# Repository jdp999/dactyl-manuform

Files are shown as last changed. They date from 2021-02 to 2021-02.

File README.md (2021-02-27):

# The Dactyl-ManuForm Keyboard
This is a fork of the [Dactyl](https://github.com/adereth/dactyl-keyboard), a parameterized, split-hand, concave, columnar, ergonomic keyboard.

Imgur

The main change is that the thumb cluster was adapted from the [ManuForm keyboard](https://github.com/jeffgran/ManuForm) ([geekhack](https://geekhack.org/index.php?topic=46015.0)). The walls were changed to just drop to the floor. The keyboard is paramaterized to allow adjusting the following: 

* Rows: 4 - 6 
* Columns: 5 and up
* Row curvature
* Column curvature
* Row tilt (tenting)
* Column tilt
* Column offsets
* Height

I built a 4x5 version (40% size) for myself. The default has a bit more tenting than the Dactyl. See the following model files for configurations that may be most common:

* [40% size, (4x5)](https://github.com/tshort/dactyl-keyboard/blob/master/things/right-4x5.stl)
* [60% size, (5x6)](https://github.com/tshort/dactyl-keyboard/blob/master/things/right-5x6.stl)

## Assembly

### Generating a Design

**Setting up the Clojure environment**
* [Install the Clojure runtime](https://clojure.org)
* [Install the Leiningen project manager](http://leiningen.org/)
* [Install OpenSCAD](http://www.openscad.org/)

**Generating the design**
* Run `lein repl`
* Load the file `(load-file "src/dactyl_keyboard/dactyl.clj")`
* This will regenerate the `things/*.scad` files
* Use OpenSCAD to open a `.scad` file.
* Make changes to design, repeat `load-file`, OpenSCAD will watch for changes and rerender.
* When done, use OpenSCAD to export STL files

**Tips**
* [Some other ways to evaluate the clojure design file](http://stackoverflow.com/a/28213489)
* [Example designing with clojure](http://adereth.github.io/blog/2014/04/09/3d-printing-with-clojure/)

### Printing
Pregenerated STL files are available in the [things/](things/) directory. 
When a model is generated, it also generates a `.scad` model for a bottom plate. 
This can be exported to a DXF file in OpenSCAD.
The [things/](things/) directory also has DXF files for the bottom plate.
When laser cut, some of the inside cuts will need to be removed. 

This model can be tricky to print. 
It's wide, so I've had problems with PLA on a Makerbot with edges warping. 
This can cause the printer to think its head is jammed. 
Even if it successfully prints, warping can cause problems. 
On one print, the RJ-9 holder was squished, so I had to cut down my connector to fit.

If printed at Shapeways or other professional shops, I would not expect such problems. 

### Thingiverse

[The 4x5 STL left/right pair](https://www.thingiverse.com/thing:2349390) from the [things/](things/) directory is in the thingiverse for public printing

### Wiring

Here are materials I used for wiring.

* Two Arduino Pro Micros
* [Heat-set inserts](https://www.mcmaster.com/#94180a331/=16yfrx1)
* [M3 wafer-head screws, 5mm](http://www.metricscrews.us/index.php?main_page=product_info&cPath=155_185&products_id=455)
* [Copper tape](https://www.amazon.com/gp/product/B009KB86BU)
* [#32 magnet wire](https://www.amazon.com/gp/product/B00LV909HI)
* [#30 wire](https://www.amazon.com/gp/product/B00GWFECWO)
* [3-mm cast acrylic](http://www.mcmaster.com/#acrylic/=144mfom)
* [Veroboard stripboard](https://www.amazon.com/gp/product/B008CPVMMU)
* [1N4148 diodes](https://www.amazon.com/gp/product/B00LQPY0Y0)
* [Female RJ-9 connectors](https://www.amazon.com/gp/product/B01HU7BVDU/)

I wired one half using the traditional approach of using the legs of a diode to form the row connections. 
(I'm not great at soldering, so this was challenging for me.)
For this side, I used magnet wire to wire columns. That worked okay. 
The magnet wire is small enough, it wants to move around, and it's hard to tell if you have a good connection.

Imgur

For another half, I used stripboard for the row connections. 
This allowed me to presolder all of the diodes. 
Then, I hot-glued this in place and finished the soldering of the other diode ends. 
I like this approach quite a lot. 
Connections for the diodes were much easier with one end fixed down. 
On this half, I also used copper tape to connect columns. 
This worked a bit better than the magnet wire for me. 
For a future version, I may try just bare tinned copper wire for columns (something like #20). 
With the stripboard, it's pretty easy keeping row and column connections separate.

Imgur

Note that a telephone handset cable has leads that are reversed, so take this into account when connecting these leads to the controller.

The 3D printed part is the main keyboard. 
You can attach a bottom plate with screws. 
The case has holes for heat-set inserts designed to hold 3- to 6-mm long M3 screws. 
Then, I used wafer-head screws to connect a bottom plate. 
If wires aren't dangling, a bottom plate may not be needed. 
You need something on the bottom to keep the keyboard from sliding around. 
Without a plate, you could use a rubber pad, or you could dip the bottom of the keyboard in PlastiDip.

For more photos of the first complete wiring of v0.4, see [Imgur](http://imgur.com/a/v9eIO).

This is how the rows/columns wire to the keys and the ProMicro
Wire Diagram

#### Alternative row-driven wiring diagram for ProMicro:

NOTE: you also make sure the firmware is set up correctly (ex: change row pins with col pins)

Left Wire Diagram

Left Wire Diagram


### Firmware

Firmware goes hand in hand with how you wire the circuit. 
I adapted the QMK firmware [here](https://github.com/tshort/qmk_firmware/tree/master/keyboards/dactyl-manuform). 
This allows each side to work separately or together. 
This site also shows connections for the Arduino Pro Micro controllers.

## License

Copyright © 2015-2017 Matthew Adereth and Tom Short

The source code for generating the models (everything excluding the [things/](things/) and [resources/](resources/) directories is distributed under the [GNU AFFERO GENERAL PUBLIC LICENSE Version 3](LICENSE).  The generated models and PCB designs are distributed under the [Creative Commons Attribution-NonCommercial-ShareAlike License Version 3.0](LICENSE-models).

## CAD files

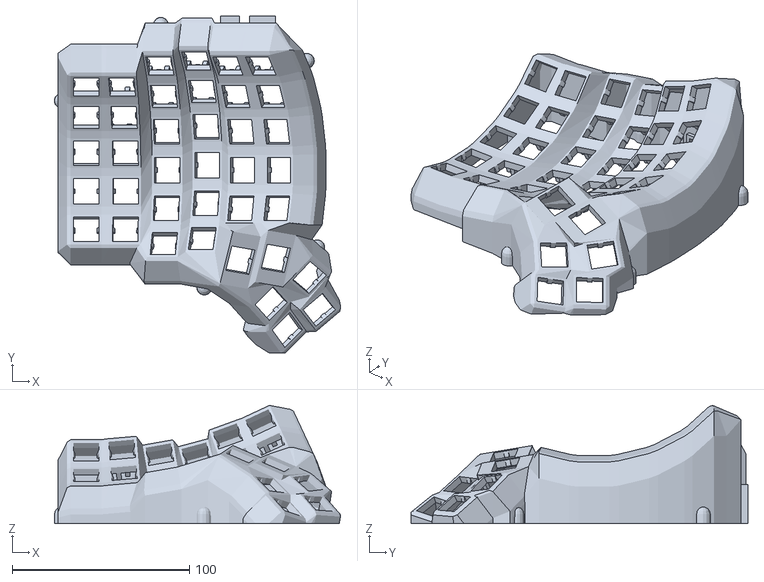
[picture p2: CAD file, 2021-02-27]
things/left-6x6.stl
161.7 x 190.2 x 66.8

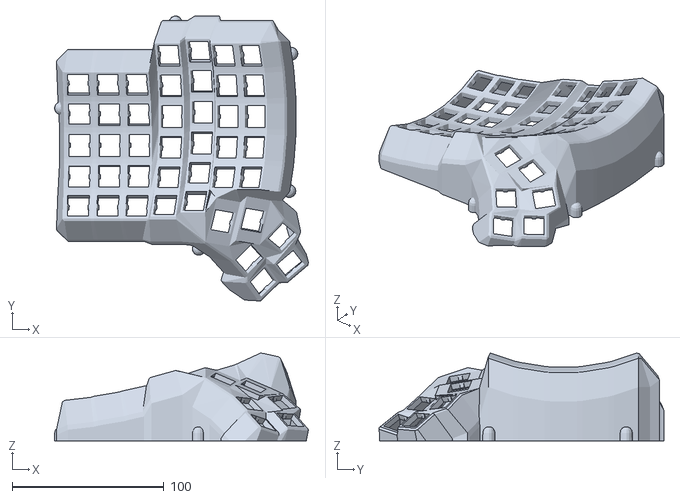
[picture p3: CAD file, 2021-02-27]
things/left6x7-tuned.stl
167.3 x 187.6 x 57.9

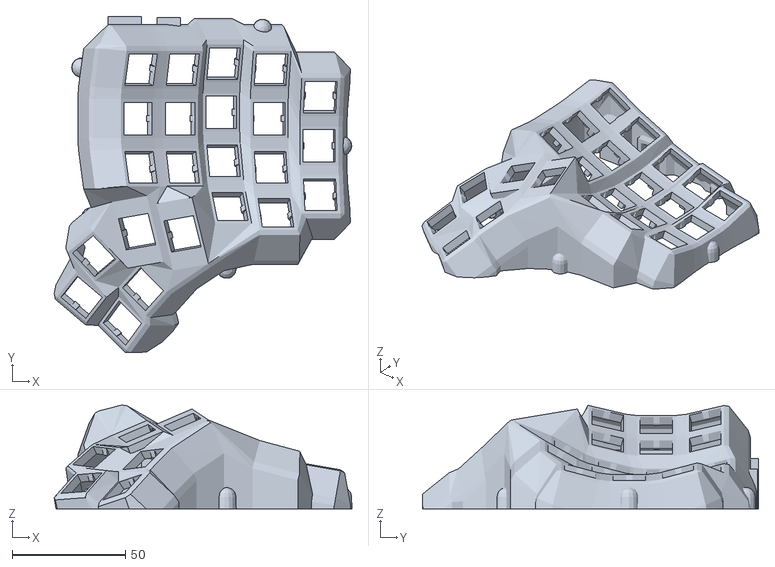
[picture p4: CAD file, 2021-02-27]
things/right-4x5.stl
131.5 x 148.4 x 45.8

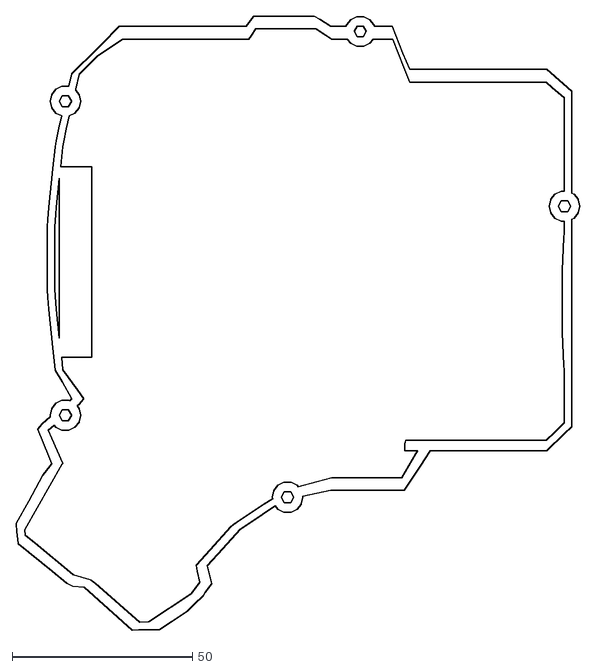
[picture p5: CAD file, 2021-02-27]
things/right-5x6-plate.dxf
156.5 x 170.5

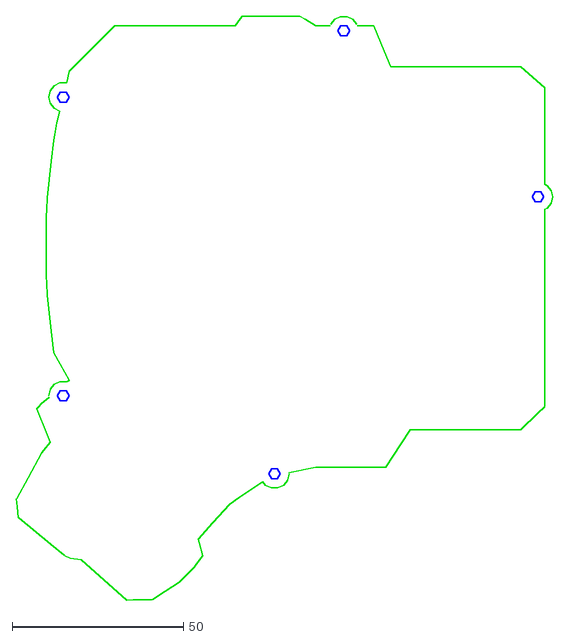
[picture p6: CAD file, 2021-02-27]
things/right-5x6-plate-ready-to-cut.dxf
156.5 x 170.5

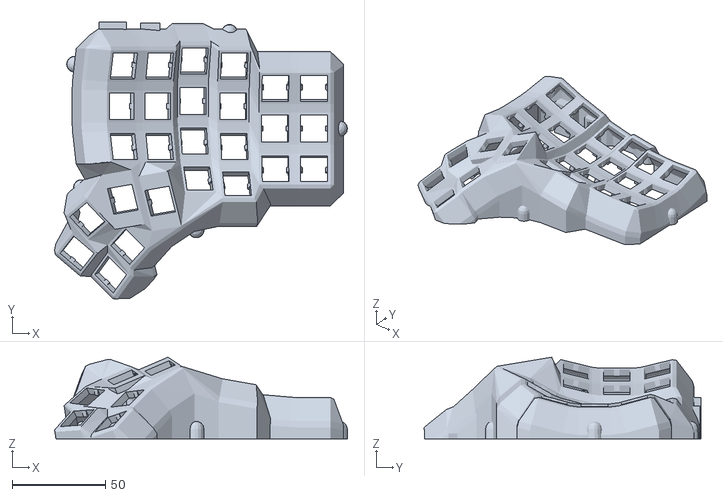
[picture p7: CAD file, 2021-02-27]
things/right-4x6.stl
157.2 x 148.4 x 43.8

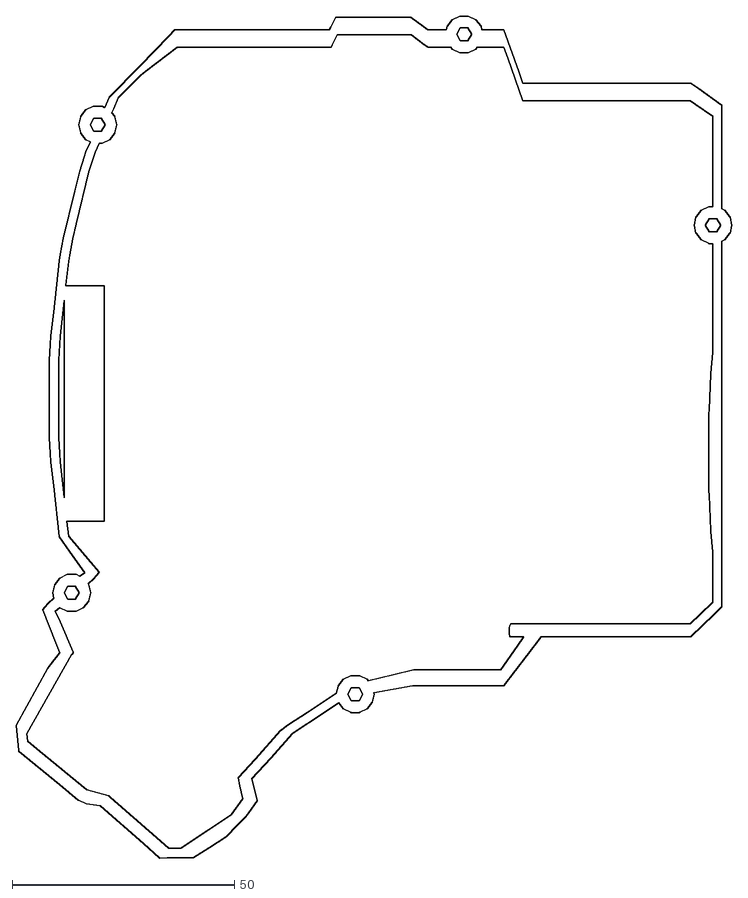
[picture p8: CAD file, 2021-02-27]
things/right-6x6-plate.dxf
160.9 x 189.3

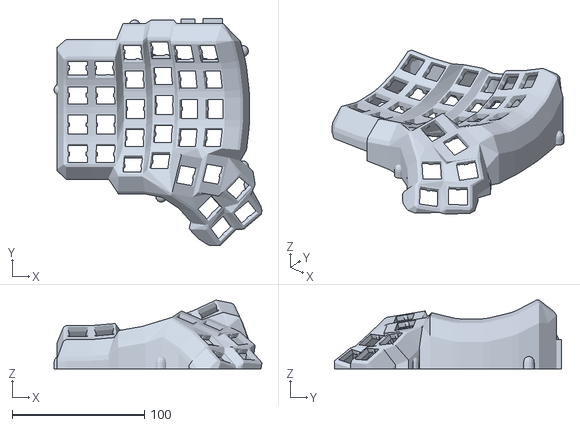
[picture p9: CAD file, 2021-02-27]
things/left-5x6.stl
157.2 x 171.5 x 52.1

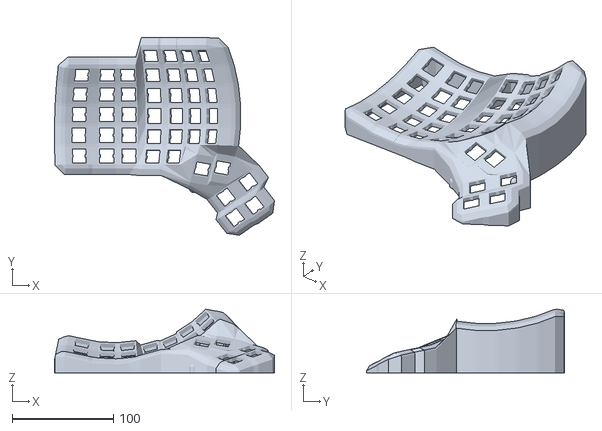
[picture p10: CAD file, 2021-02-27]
things/left6x7-MOD2.stl
216.9 x 194.8 x 62.7

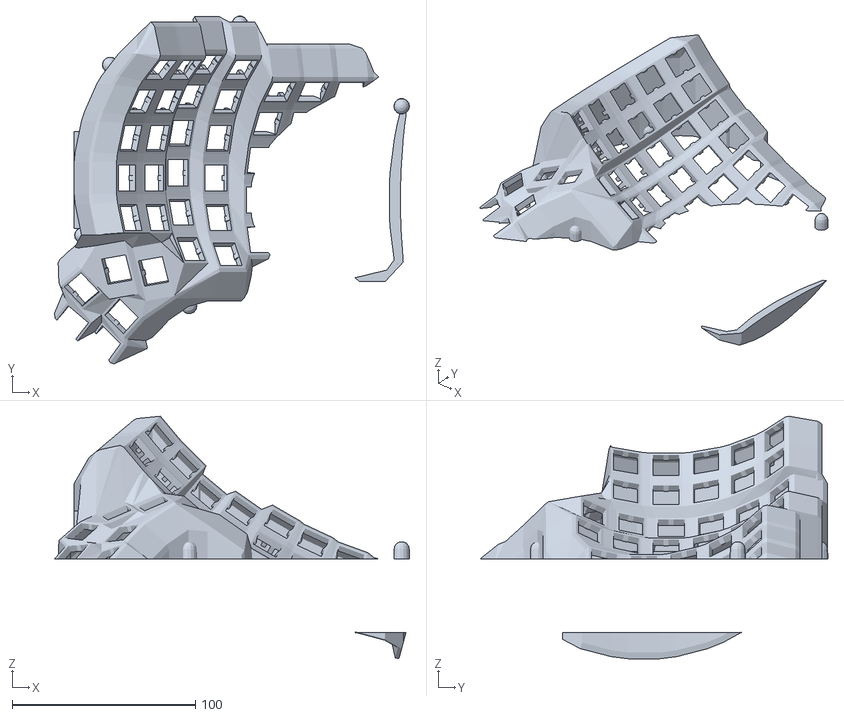
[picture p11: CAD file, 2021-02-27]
things/right6x8.stl
193.5 x 189.5 x 132.2

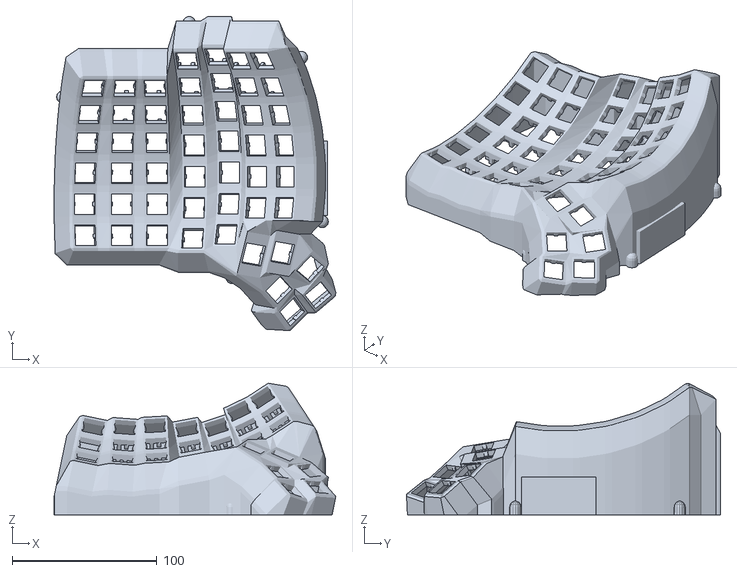
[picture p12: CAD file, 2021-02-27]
things/left7x7.stl
194.4 x 216.7 x 90.8

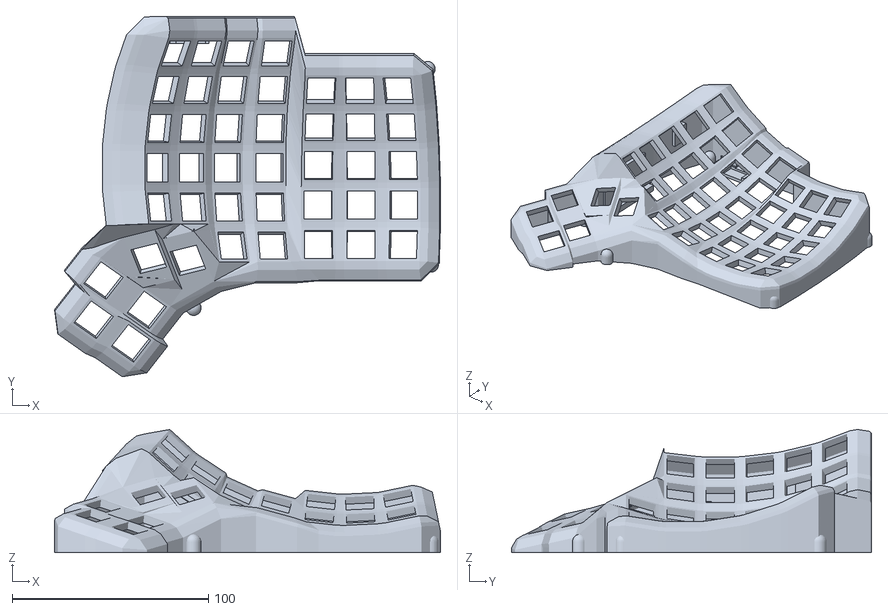
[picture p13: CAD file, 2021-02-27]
things/right6x7_short.stl
196.8 x 183.8 x 62.7

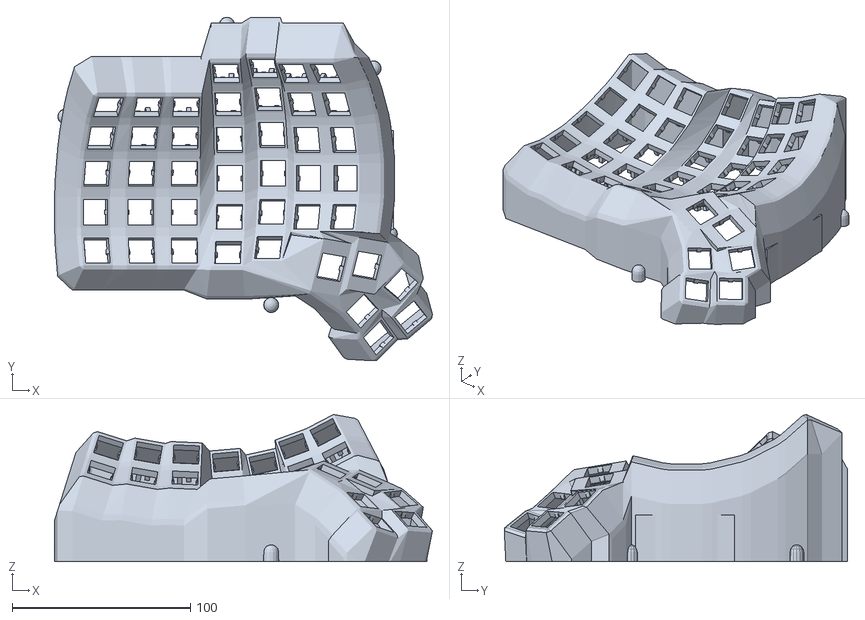
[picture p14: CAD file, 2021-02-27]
things/left6x7.stl
212.0 x 192.6 x 82.5

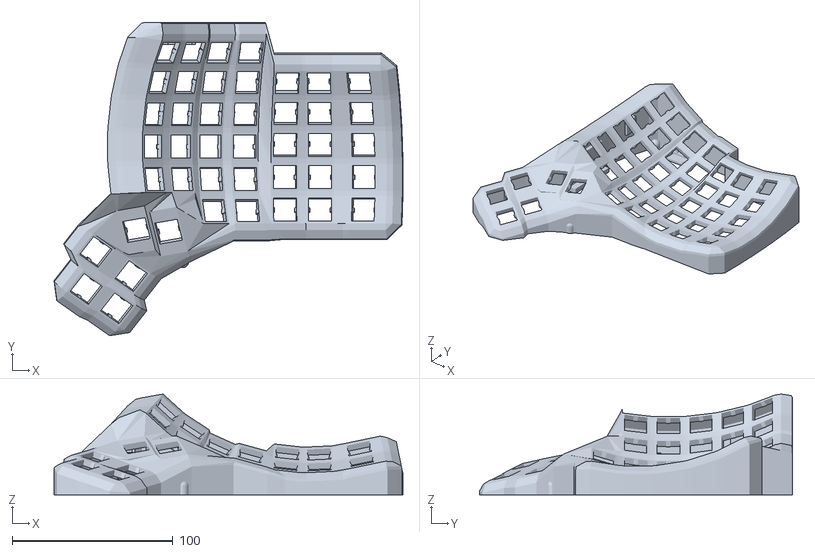
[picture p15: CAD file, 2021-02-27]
things/right6x7-MOD2stl.stl
216.9 x 194.8 x 62.7

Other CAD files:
things/right.6x7_tuned.stl
things/left-4x6.stl
things/left-4x5.stl
things/right7x7.stl
things/left6x7_short.stl
things/right-4x5-plate.dxf
things/right-4x6-plate.dxf
things/right-5x6.stl
things/right-6x6.stl
things/right-plate.dxf
things/right.stl
things/right6x7-MOD1.stl
things/right6x7.stl

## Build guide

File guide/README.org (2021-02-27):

* Preparation and Cost
  Get all the parts / raw material:
  - For the 3D printing there are two options:
    1. Filament, which is the basis for 3D printing. Luckily I could print at my work-place
       which reduced the cost from 210€ to 70€. The kind of filament you need depends on the 3D
       printer you have available.
    2. Buy the printout of adareth's model at shapeways for 210€ over here
       http://www.shapeways.com/designer/adereth/creations
  - Decide on the switches
    - If you are going to invest a whole lot of time and money for a custom keyboard instead of
      buying one for 10€ I'd recommend to use your favorite switch-type. To make a
      well-informed decision I bought a switch-tester for this from massdrop and decided on
      Cherry MX Whites. https://www.massdrop.com/buy/varmilo-switch-tester-with-anodized-case
    - I ordered 70 Cherry MX Whites from here:
      https://mechanicalkeyboards.com/shop/index.php?l=product_detail&p=847
  - Decide on the key caps
    - On the glamour-Shot you can see the 1976 keycap set, it used to be sold over here:
      http://pimpmykeyboard.com/sa-1976-keycap-set/ but the link is dead right now. You could
      try this link: https://www.massdrop.com/buy/nineteenseventysix-sa-keycap-set but it is a
      massdrop which is way different from usual online-stores. If you find a site that sells
      these make sure you get the right amount and type of keys according to the layout
    - I got the "TKL Base Set + TKL Modifier" from over here:
      http://pimpmykeyboard.com/dsa-pbt-abs-blank-keycap-sets/ but I'm still two long keys
      short, I will have to order those specifically and I have a bunch of keys I don't use
      left-over.
  - The USB-Cable that connects the keyboard to your computer
    - It's an USB 2.0 to USB Mini-B cable, make sure you get one that is 2 meters long, it
      really makes handling the keyboard so much more comfortable
    - https://www.amazon.de/gp/product/B00NH11N5A/
  - The main controller (right half)
    - A Teensy 2.0, I got that one from here: https://www.pjrc.com/store/teensy.html
  - The chip, connectors and cable to give life to the left half
    - TTRS cable and jacks
      - Got my TTRS cable from here: http://www.digikey.de/product-search/de?keywords=839-1257-ND
      - Got my TTRS jacks from here: http://www.digikey.de/product-search/de?keywords=CP-43514-ND
    - MCP23018 16 bit IO Expander
      - Got mine from here: http://www.digikey.de/product-search/de?keywords=MCP23018-E%2FSP-ND

  What I spend on my keyboard (should give you a rough estimate for your build):
  | item                              | cost |
  |-----------------------------------+------|
  | filament                          |   70 |
  | switch-tester                     |   30 |
  | key-caps                          |   70 |
  | teensy 2.0                        |   30 |
  | switches                          |   60 |
  | usb cable                         |   10 |
  | IO Expander, TTRS jacks and cable |   30 |
  |-----------------------------------+------|
  | overall cost                      |  300 |
  #+TBLFM: @9$2=vsum(@2$2..@8$2)

  My choices / advantages:
  - Using the soldering iron at the uni-workshop for free
  - 76 Diodes for free
  - Soldering wire and copper for free
  - All the resistors used for free (5 resistors are used)
  - Several files for working out the rough edges of the 3D-printout

  Depending on what you have available you might spend more or less money than me, 300€ however
  is a good rough estimate.

  After all the parts have arrived it is safe to move on to the next section.

* Wiring
  It is assumed that you have printed the casing successfully.

  1) Plug the switches into the Casing, no glue is needed, the casing provides the perfect fit.
  2) Put the keycaps on the switches
     - Note that in the pictures here some of the long keys on the thumb-part are too short,
       that's why it doesnt look symmetrical

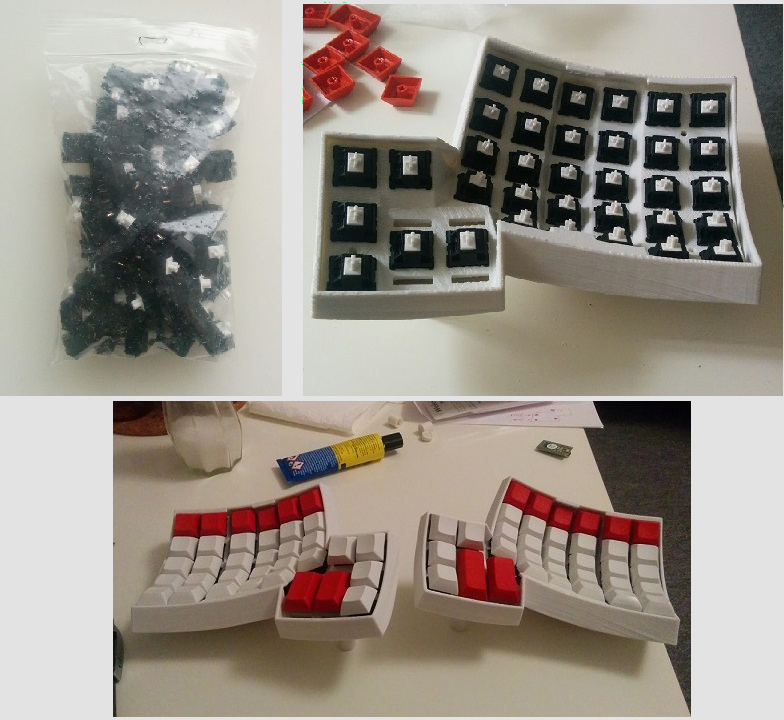
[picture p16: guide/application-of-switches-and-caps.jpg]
  

  Now going further on in the guide there are two options
  1. The first option is to print flexible PCBs. The advantage is that you save alot of wiring
     business, everything looks rather clean and you dont have to worry about your cables being too
     thick such that the casing doesnt close. However if you don't have the means to print out such
     PCBs there is the second option, wiring everything by hand.
     - The guide for this PCB-option is very rough indeed and it doesnt include the firmware
       used. Wiring and firmware play extremely close together, wiring before knowing your
       firmware is like buying a shoe without measuring your feet before. For this option
       information about the exact firmware is not published, this in addition to the fact that
       the pictures in this rough guide are incomplete makes this option extremely
       beginner-unfriendly. Going in blind-sided like this may lead to one of these things:
       1. reprogramming huge parts of the firmware to match your wiring which comes with a ton of
          debugging
       2. rewiring to adapt to what the firmware expects, which may easily double your work here
     - [[Route 1: Dactyl Flexible PCB Rough Guide]]
  2. The second option is to hand-wire everything. For people like me who had never soldered before
     this was great pain and pleasure.
     - Here too firmware and wiring go hand in hand, you pretty much have to have a detailed look
       at the firmware you are using before wiring anything. I provide my modification of the
       "ergodox-firmware" over here: https://github.com/BubblesToTheLimit/ergodox-firmware
       - TODO: Make a successfull pull-request, such that it is available in the official
         ergodox-firmware
     - Some of the steps of this guide may not be described in much detail, but in contrast to
       option one there is a whole lot more of information.
     - [[Route 2: Dactyl Hand-Wiring Guide]]

** Route 1: Dactyl Flexible PCB Rough Guide
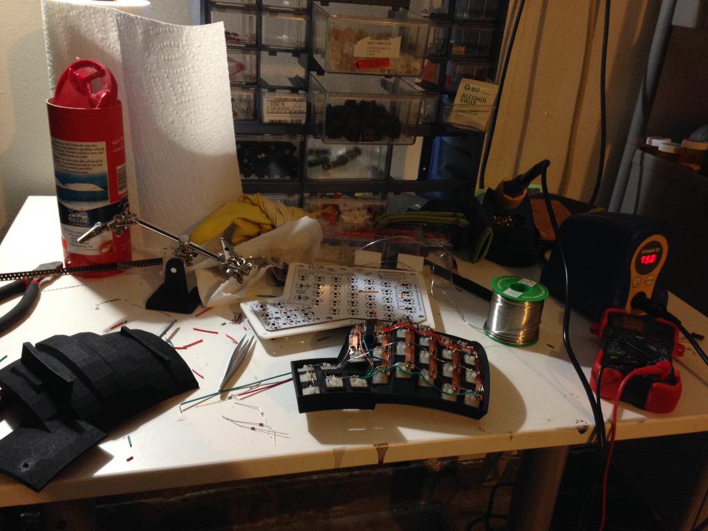
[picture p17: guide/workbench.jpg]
   

   For now, take a look at the images and try to figure things out, I know that's not great (it's
   better than nothing!)

*** Making the PCB
    Get two sheets of 6in square Pyralux™. Use the Toner Transfer method to etch the Pyralux sheets as
    you would a usual PCB

    #+BEGIN_QUOTE
    NOTE: If you only have an Inkjet make photocopies of the print out,
    voilà Toner based copies!
    #+END_QUOTE

    [[http://www.instructables.com/id/Toner-transfer-no-soak-high-quality-double-sided/][Here'sa handy toner transfer guide ...]]

    Print these PCB designs out...

    Left hand:

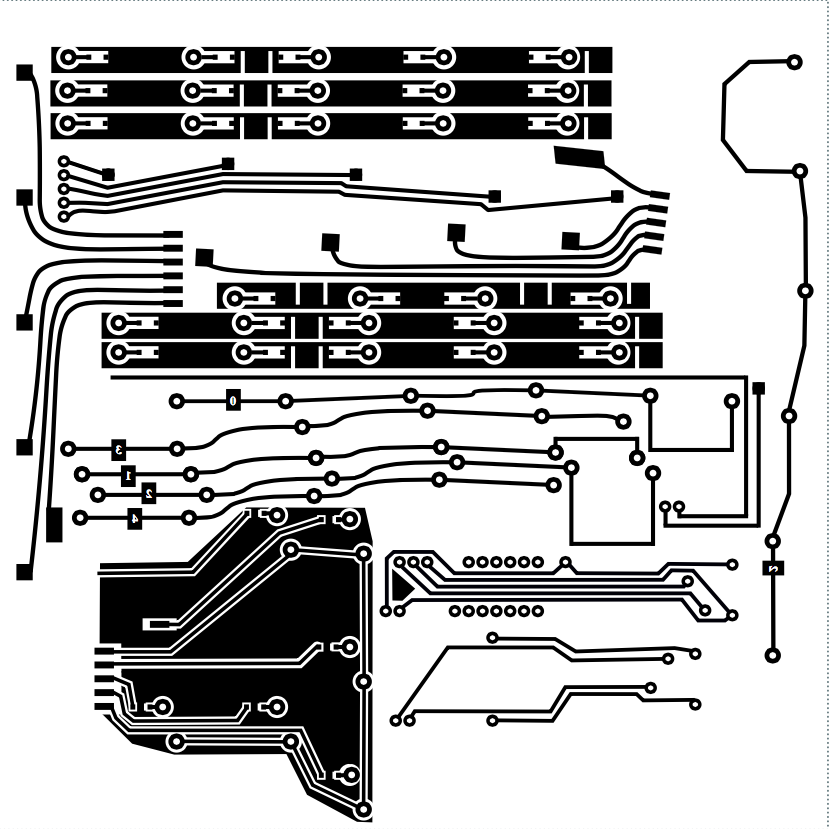
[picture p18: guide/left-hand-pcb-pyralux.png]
    

    Right hand:

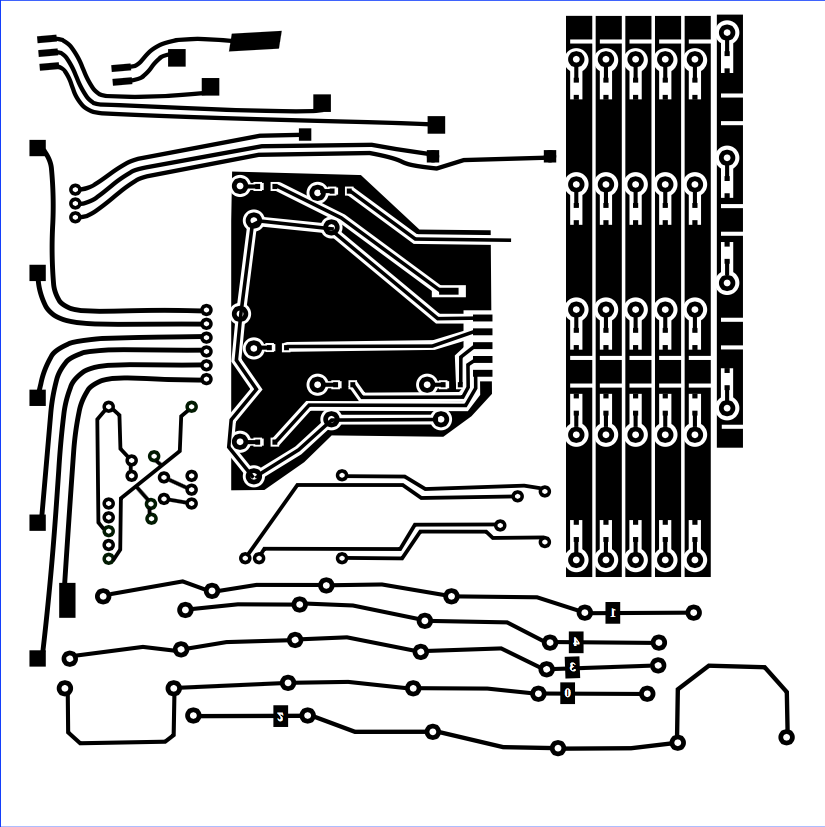
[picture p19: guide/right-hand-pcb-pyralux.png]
    

    When you're done etching, you'll need to carefully cut the pcb into pieces... See the images
    below.

*** Applying the PCB to the electronical parts
    The thumb cluster pcb for the left hand:

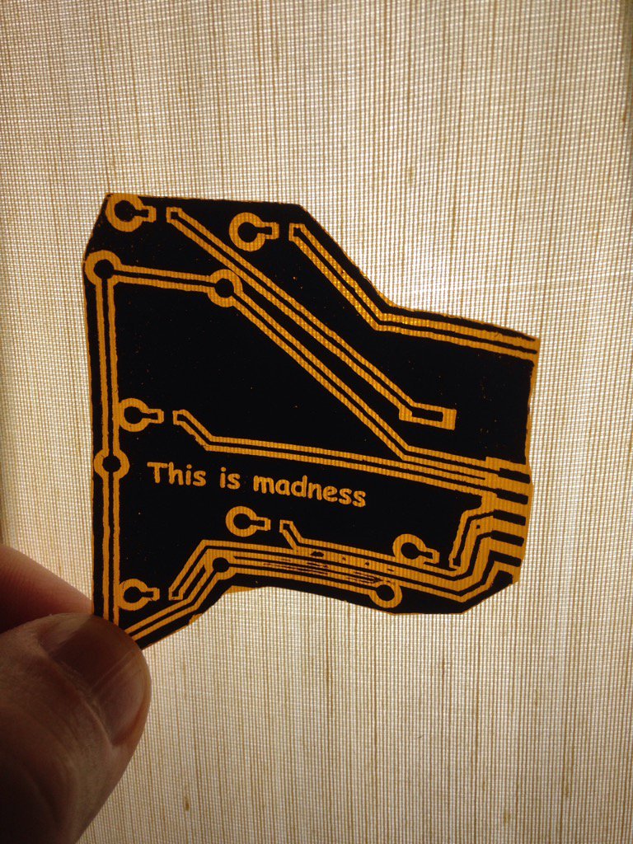
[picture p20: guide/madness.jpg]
    

    Solder the MCP like so:

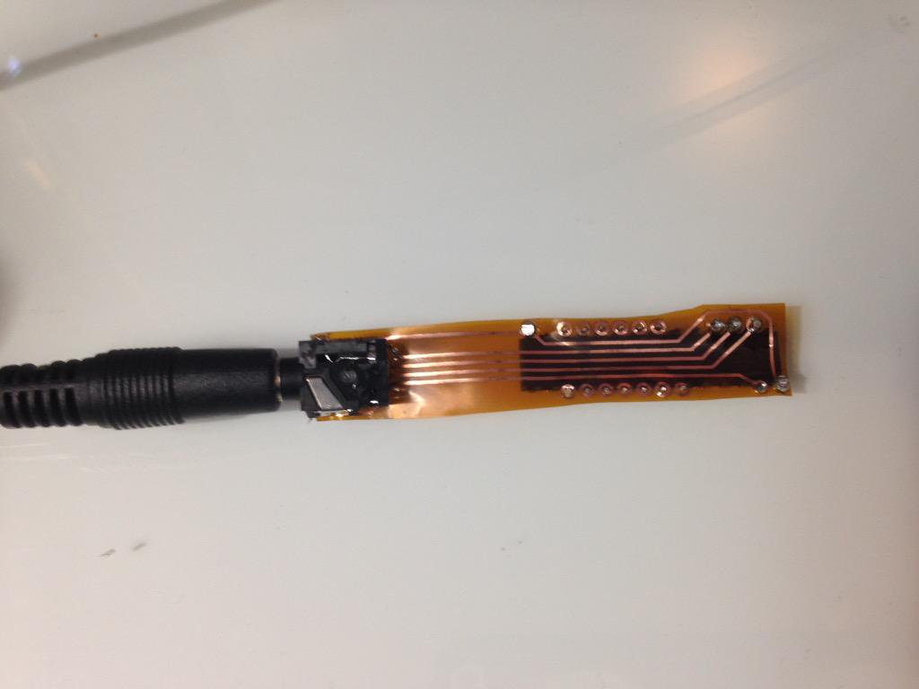
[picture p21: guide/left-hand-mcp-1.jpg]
    
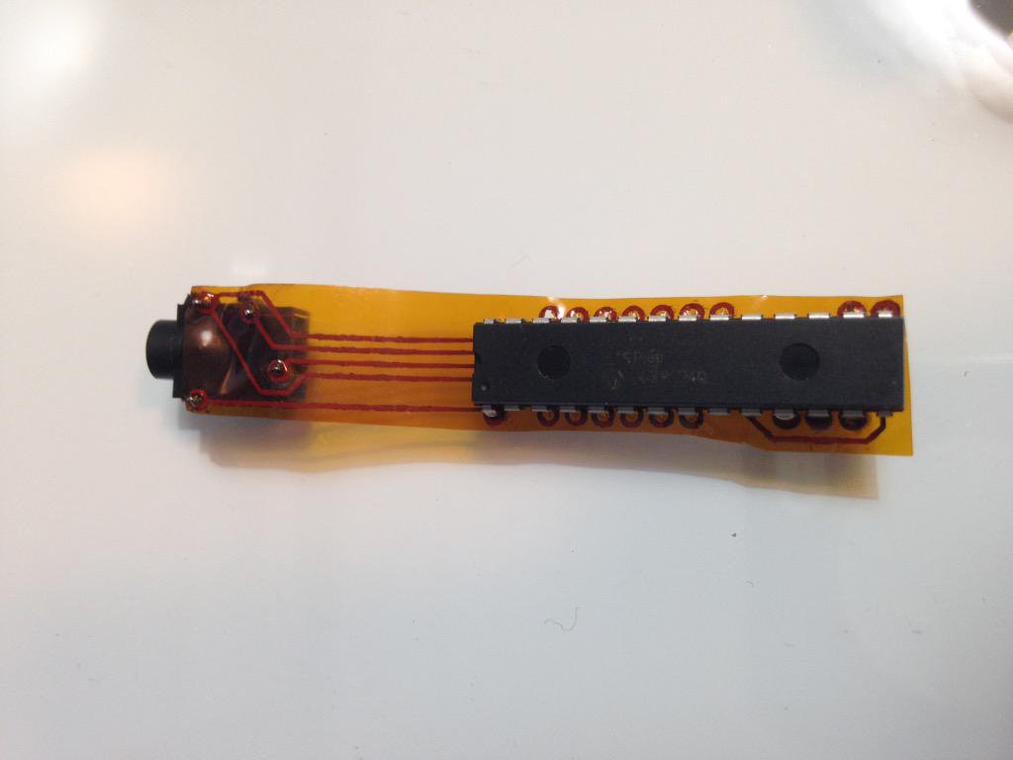
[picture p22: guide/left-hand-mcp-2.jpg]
    

    Solder the Teensy 2.0 like so:

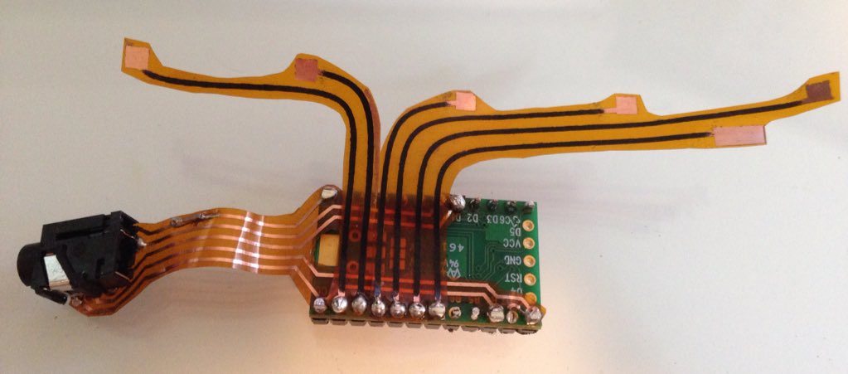
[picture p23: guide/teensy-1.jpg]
    

    Some interesting pull up 10k resistor business here... (TODO add a small diagram and notes)

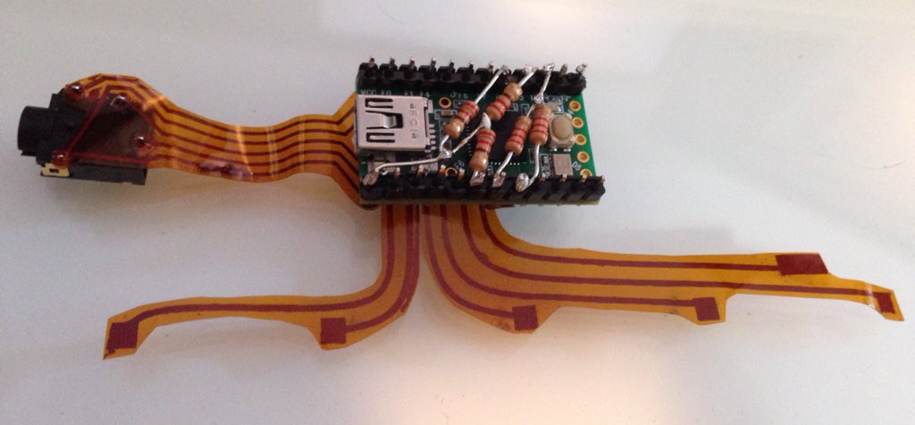
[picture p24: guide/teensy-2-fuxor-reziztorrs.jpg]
    

    Each hand of the keyboard will wire up like so:

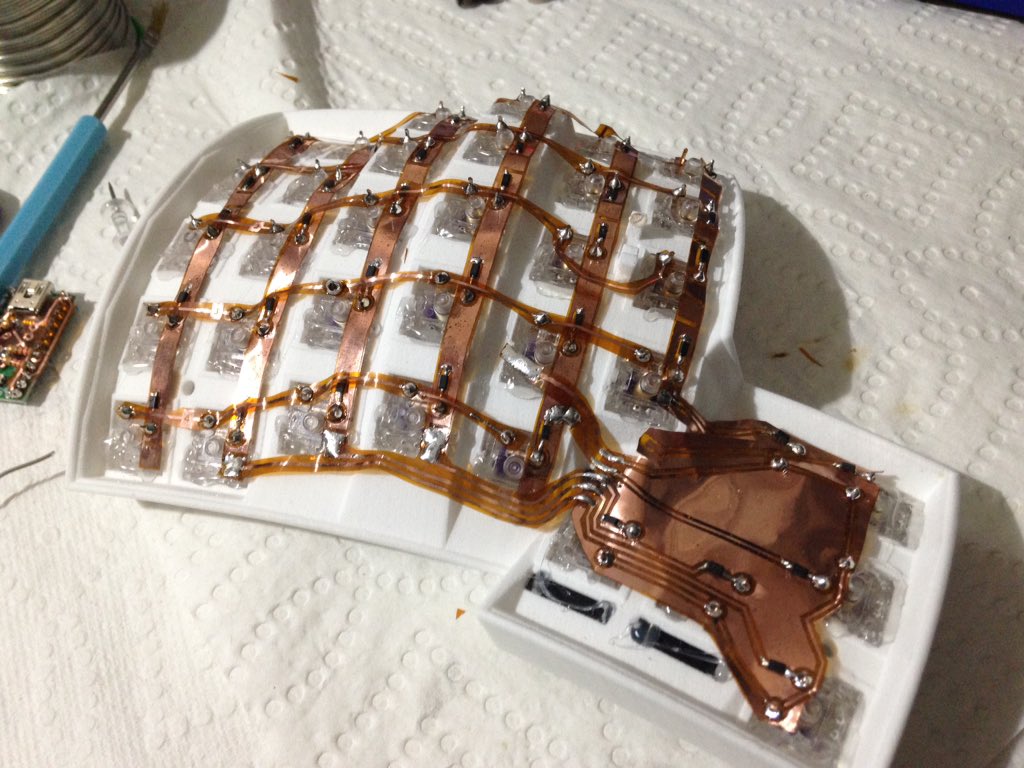
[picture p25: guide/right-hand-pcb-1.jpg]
    

    Teensy goes here... note the rows soldered to the teensy via the Pyralux:

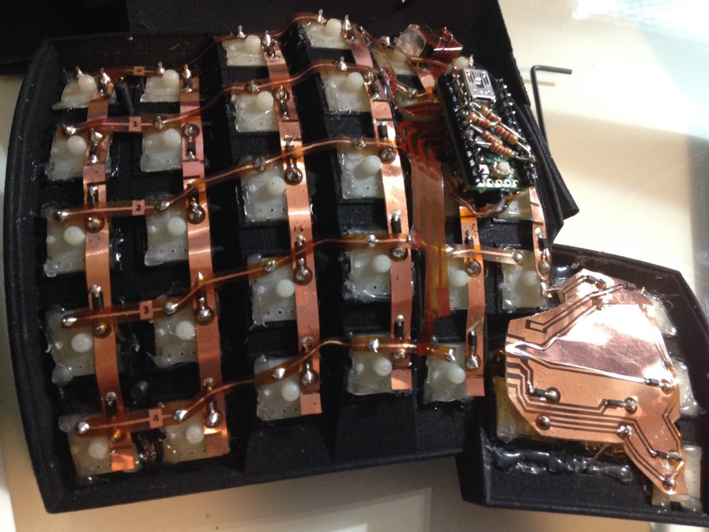
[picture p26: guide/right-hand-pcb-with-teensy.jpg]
    

    Here the left hand:

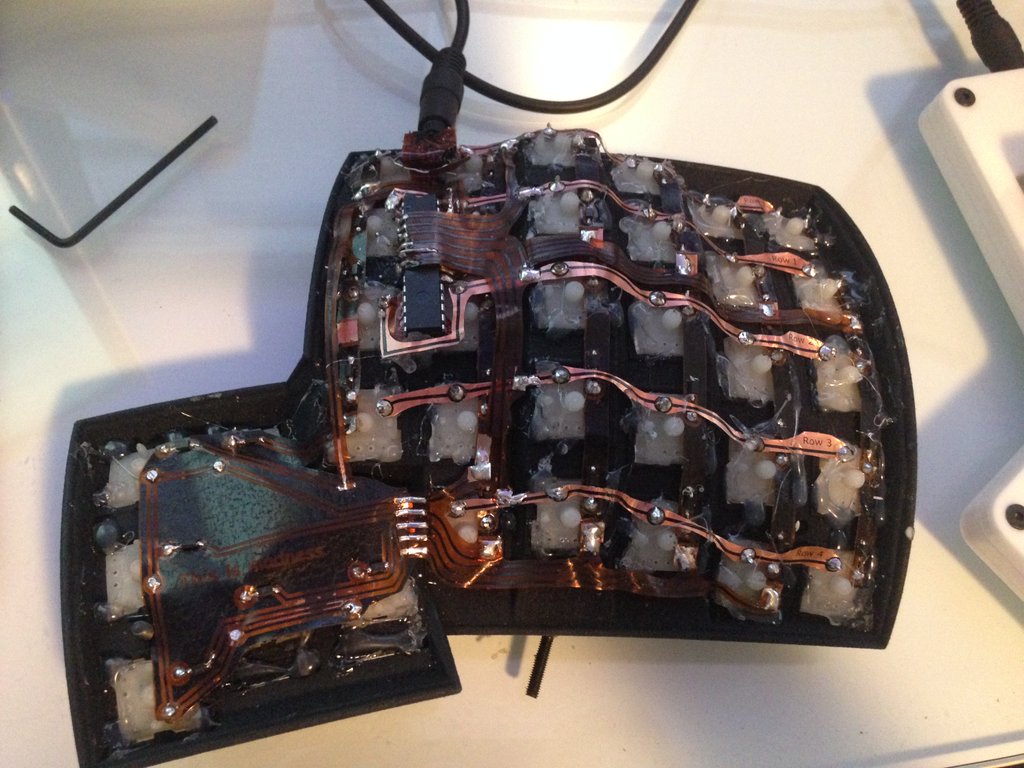
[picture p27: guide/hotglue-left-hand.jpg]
    

    That's all for now, this guide will improve over time! (TODO!)
** Route 2: Dactyl Hand-Wiring Guide
*** Step 1: Creating the rows
    Using the copper wire you solder each row together, notice how the thumb-part gets its own
    row. If you take a close look you can see how I did do a messy job soldering, I had to redo
    some of the parts because they weren't soldered properly. Do this for both sides. Which ones
    of the two available pins of each switch you chose for the row doesnt matter, but for it to
    look clean you should decide for either one of them.

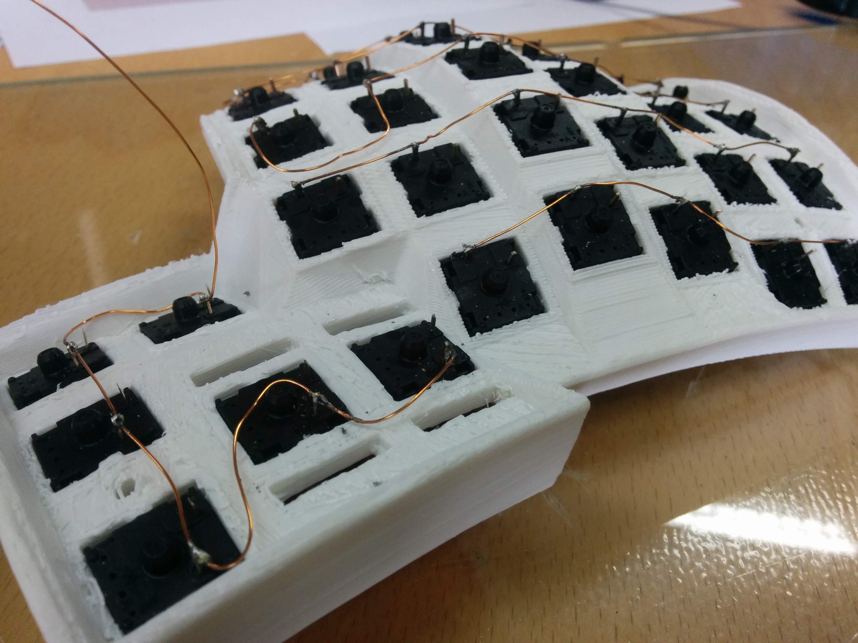
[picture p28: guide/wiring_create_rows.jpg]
    

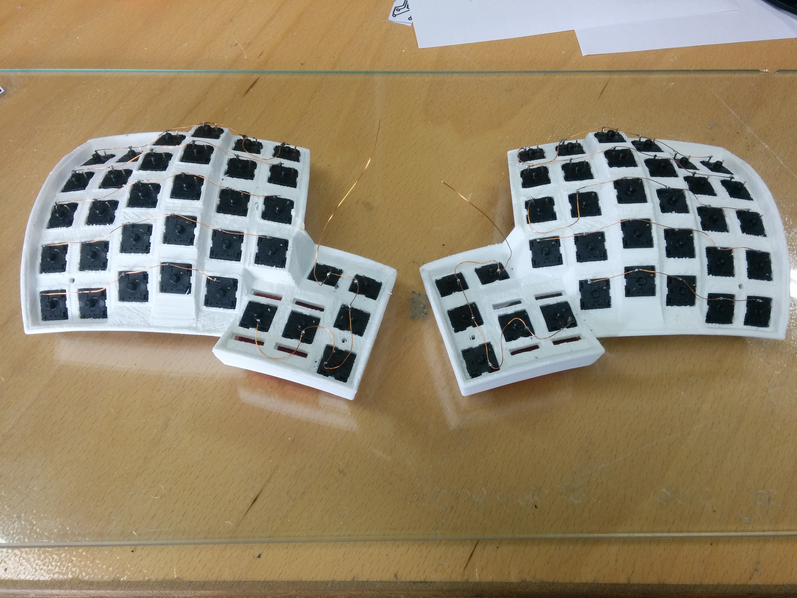
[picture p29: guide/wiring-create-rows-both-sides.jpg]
    

    You might want to go ahead and test each one of the 70 switches with a multimeter.

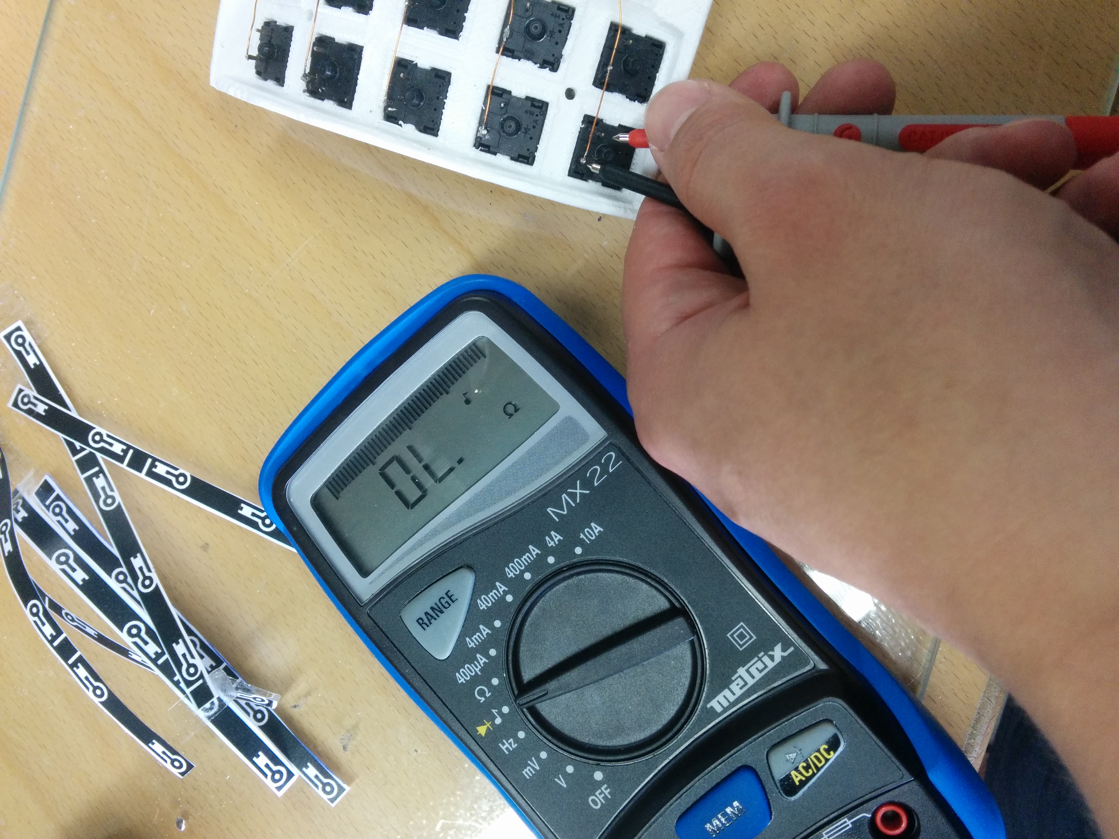
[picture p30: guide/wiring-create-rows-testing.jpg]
    

*** Step 2: Create the columns
    The next step is to create the columns by soldering the diodes. There are two options for
    soldering the diodes, all heading towards the switch or all heading away from the
    switch. These two ways are called "row-driven" or "column-driven" and here again it is
    cruciual for the firmware and the actual wiring to be on the same page.

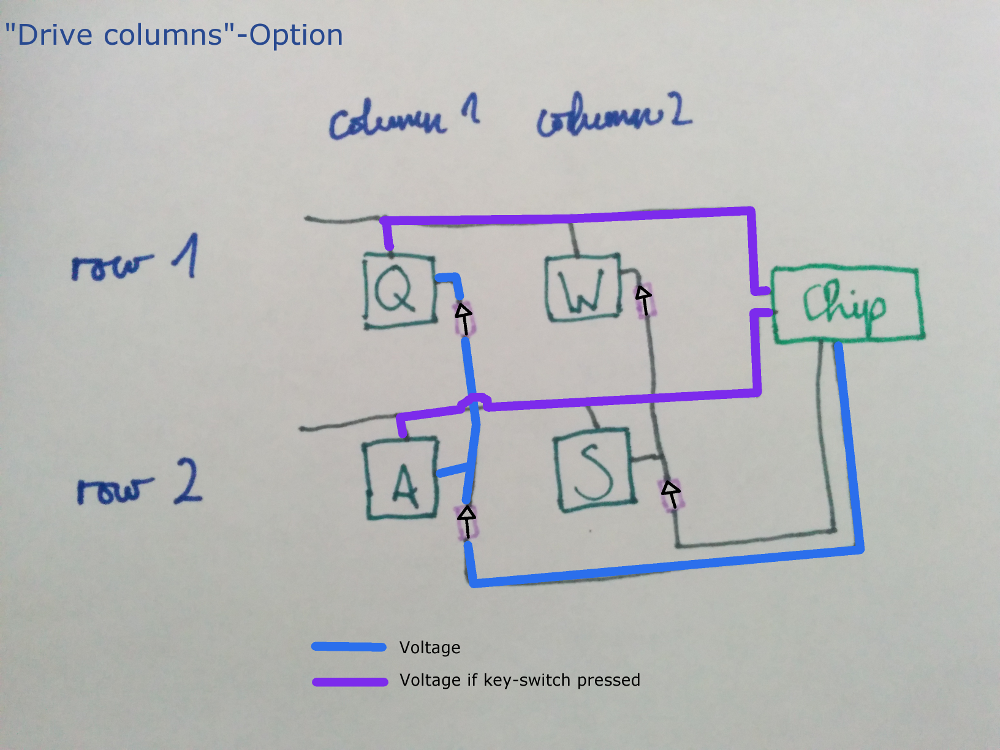
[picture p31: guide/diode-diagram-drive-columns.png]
    

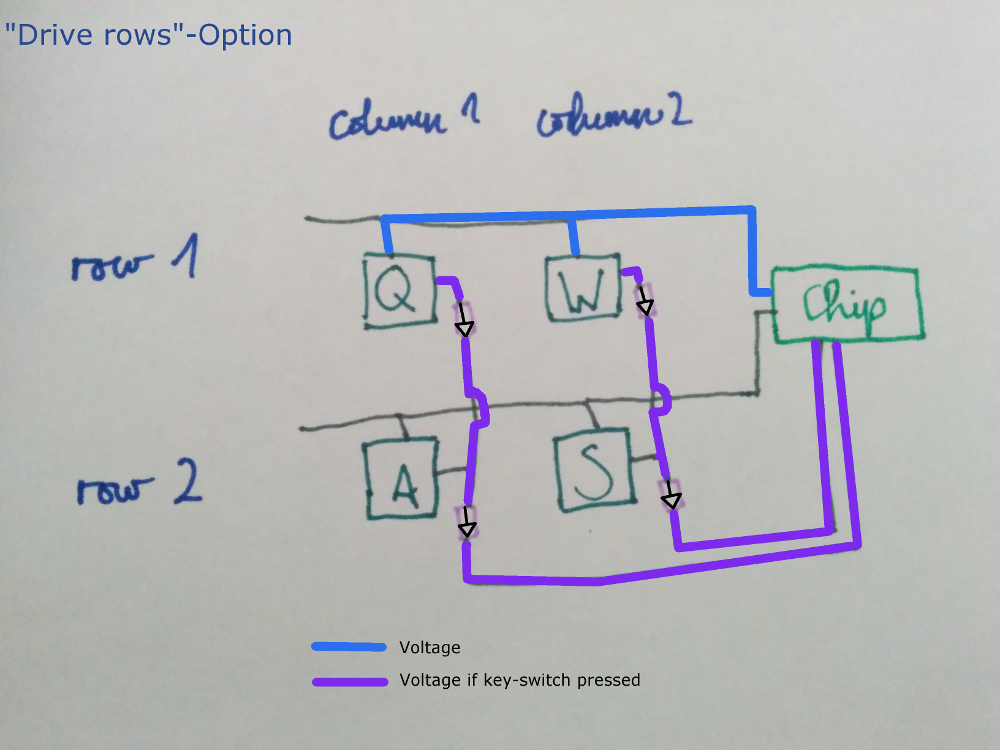
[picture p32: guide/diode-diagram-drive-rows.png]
    

    If you want to try and use the "tmk_keyboard" firmware which seems to be also interesting you
    want to wire the diodes in the according way (check whether the tmk_keyboard firmware expects
    a row-driven or a column-driven setup).

    As you can see in these following pictures I went for the "row-driven" setup (visible by the
    direction of the diodes, the black line being towards the key-switches). This first picture
    doesnt show how the 6 thumb-keys are actually individually connected to the 6 main columns,
    but note the small black line on each diode.

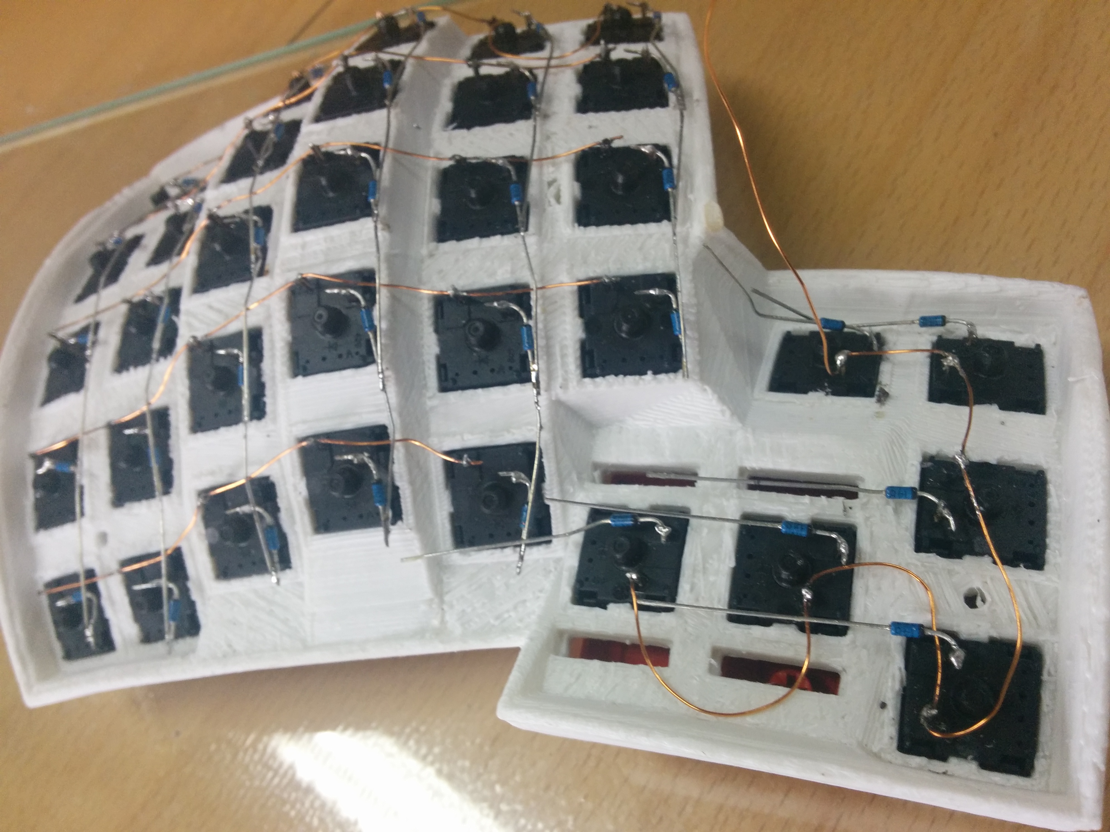
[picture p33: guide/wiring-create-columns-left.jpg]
    

    This second picture shows how the 6 thumb-keys are actually connected to the 6 main columns.

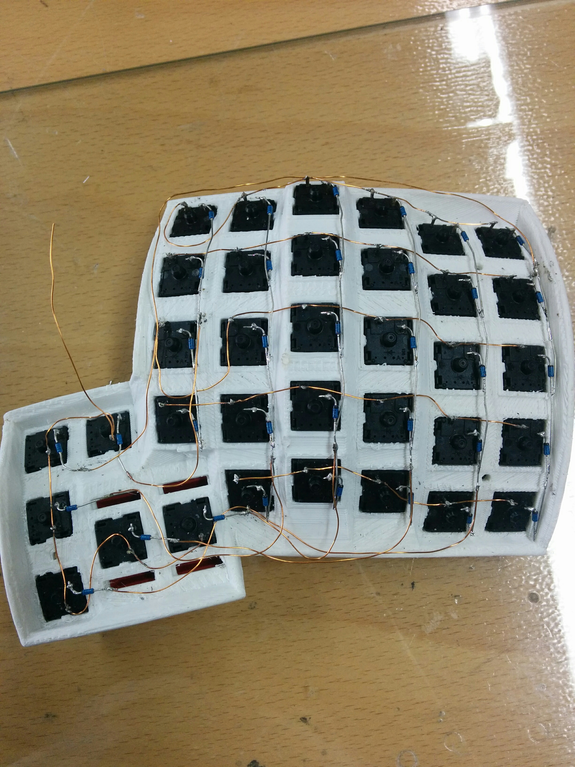
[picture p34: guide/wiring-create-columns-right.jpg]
    

    How Thumb-keys are wired again depends on the firmware, the following picture shows the wiring
    of the thumb keys more clearly and also the part in the code that reflects this wiring
    (ergodox-firmware/src/keyboard/dactyl/matrix.h).

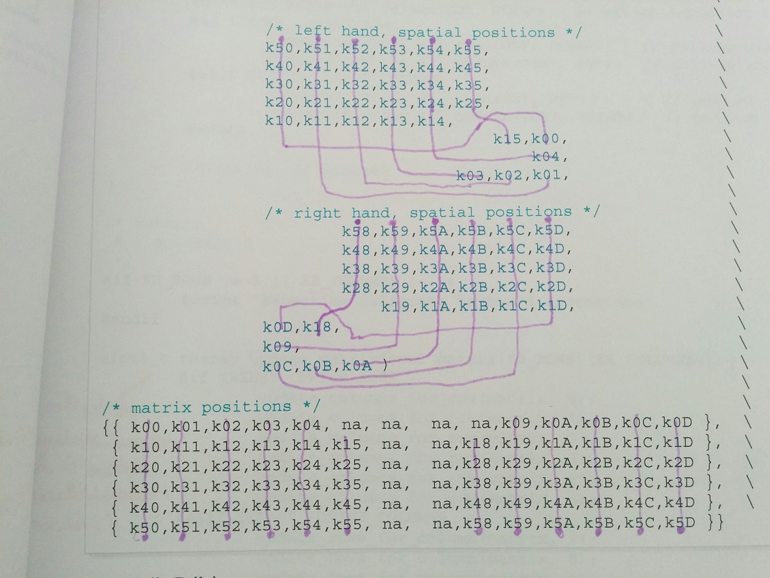
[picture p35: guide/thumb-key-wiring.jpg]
    

*** Step 3: Put the Teensy and the MCP in place
    This next step is to wire the Teensy 2.0 and the MCP 23018 in place.
    Everything necessary for that really is the following circuit diagram

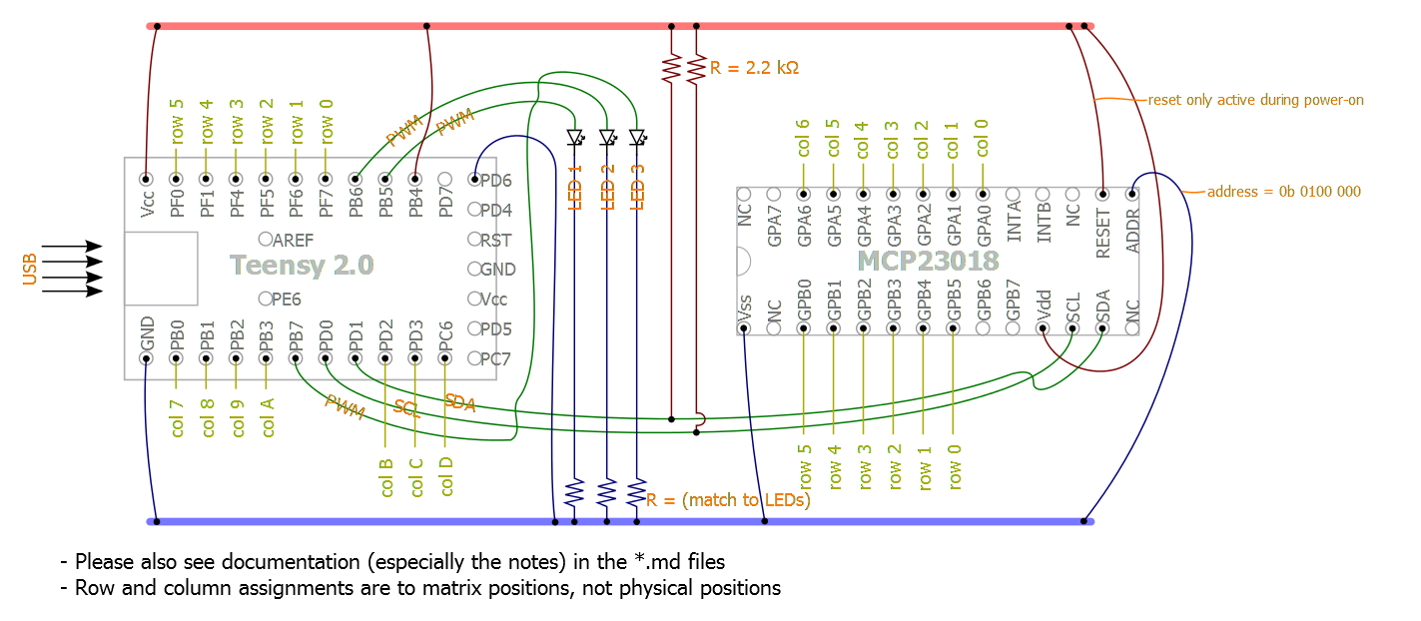
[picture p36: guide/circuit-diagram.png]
    

    Things to note here:
    - The columns for the MCP go from 0 to 6, the columns for the Teensy go from 7 to D (counting
      in hexadecimal) which makes great sence, since the MCP is left to the Teensy and we read from
      left to right.
    - When debugging this and using the ergodox-firmware, both sides have to be wired completely
      and actually with the TTRS connected, dont expect the keyboard to work before that. The reason being is how
      the ergodox-firmware stops completely if either the Teensy or the MCP weren't initiated
      properly.
    - In the circuit-diagram the columns on the left side (MCP side) actually go from GPA5 to INTA
      (TODO: Update the circuit diagram and get rid of this point)
    - The LEDs are handy for debugging, definately go ahead and connect those. When the keyboard
      starts successfully two of the LEDs light up shortly.
    - From the Teensy over to the MCP go exactly 4 connections. The blue, the red and the two green
      ones. This is done using the TTRS jacks and cable.
    - Yes, the connection from B4 to VCC doesnt seem to make any sense, but the B4 port actually
      gets used directly in the ergodox-firmware, so just connect those connections that make no
      sense on first sight and either dont question it or find out why this is necessary by going
      through the firmware in great detail.

    This is how the trrs jacks are wired:

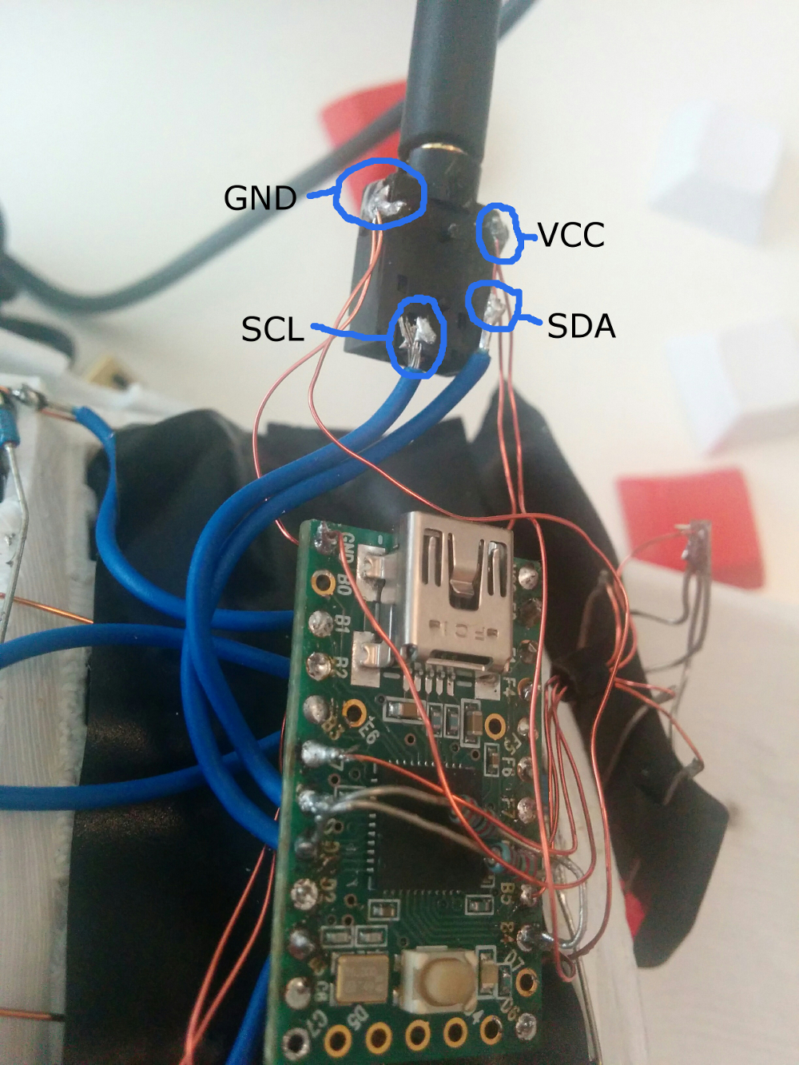
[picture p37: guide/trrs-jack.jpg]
    

    After you are done you might have the following result:

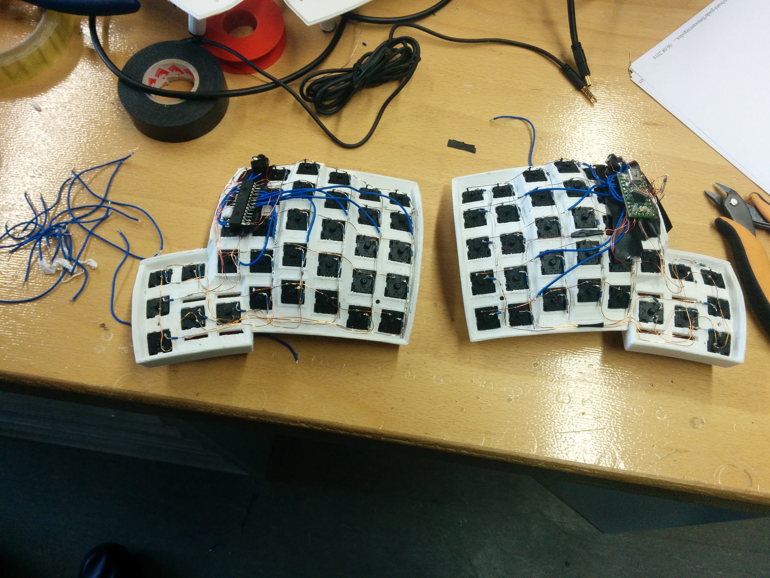
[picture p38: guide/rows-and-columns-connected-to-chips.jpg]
    

    Good luck!
